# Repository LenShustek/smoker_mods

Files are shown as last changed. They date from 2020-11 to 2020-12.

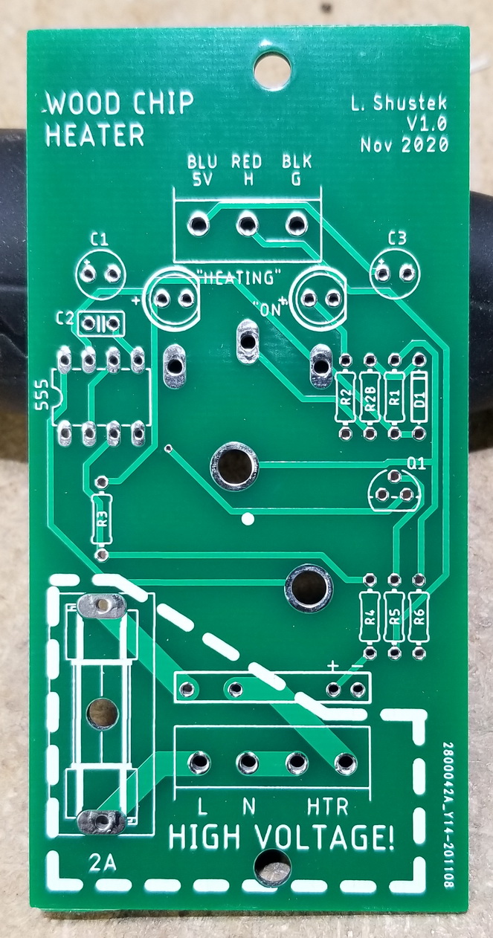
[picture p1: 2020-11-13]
chipheater/photos/PC_board.jpg

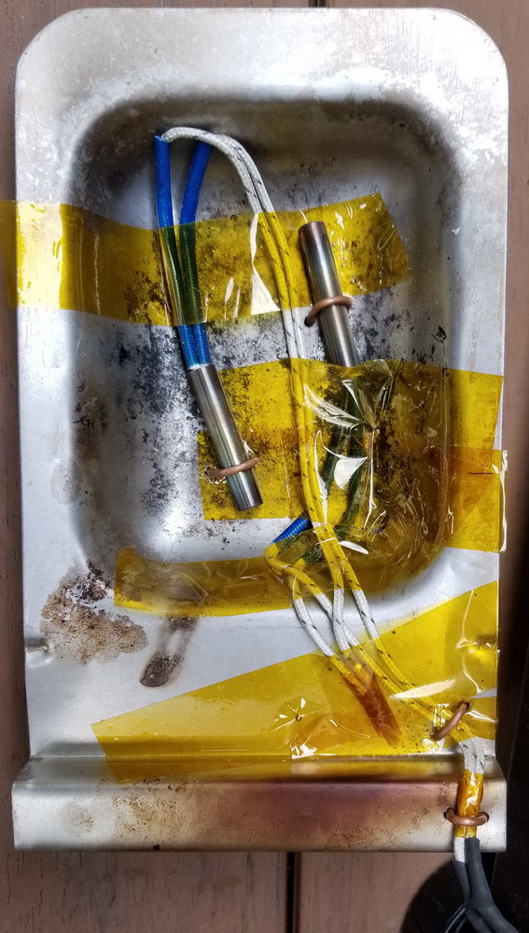
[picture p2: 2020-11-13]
chipheater/photos/chip_tray.jpg

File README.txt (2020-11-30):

This is a repository that documents my modifications to the 
Masterbuilt MES130B food smoker. 

It's a serviceable appliance, and we've made some great meals with it, 
but it suffers from a number of defects. You can read my posting to 
www.smokingmeatforums.com about them in the file forum_posting.txt. 

The first modification I made is to keep the smoke production going 
when the main (and only) heating element turns off to allow the 
temperature to come down. I put some heating elements in the bottom of 
the wood chip tray, and turn them on periodically whenever the main 
heater is off. 

The details are in the chipheater directory. There are two 100W heating 
elements wired in series, so 50W power dissipation. To control them I 
tapped into the 4-wire cable (ground, 5VDC power, heater on, and 
temperature sense) that goes to Masterbuilt's controller, and connected 
a little circuit that switches a small solid-state relay. A knob adjusts 
the duty cycle: it's on for 10 seconds and off for 2 to 18 seconds. It 
seems to be working fine. 

The second modification was to replace the Masterbuilt controller with
one based on an inexpensive PID (proportional-integral-differential) 
controller, interfaced to the smoker with a small circuit. This keeps
the temperature at the set point within a degree or two, rather than
having huge overshoot and undershoot by 10-15 degrees in each direction, 
with a cycle time of about 15 minutes. 

The details are in the PID_interface directory. In particular, see
the PID_addition_instructions file for instructions and photos.
This modification doesn't require the smoker unit itself to be
taken apart, or any of its 120V AC wiring changed.

Len Shustek 13 November 2020 
updated 29 November 2020

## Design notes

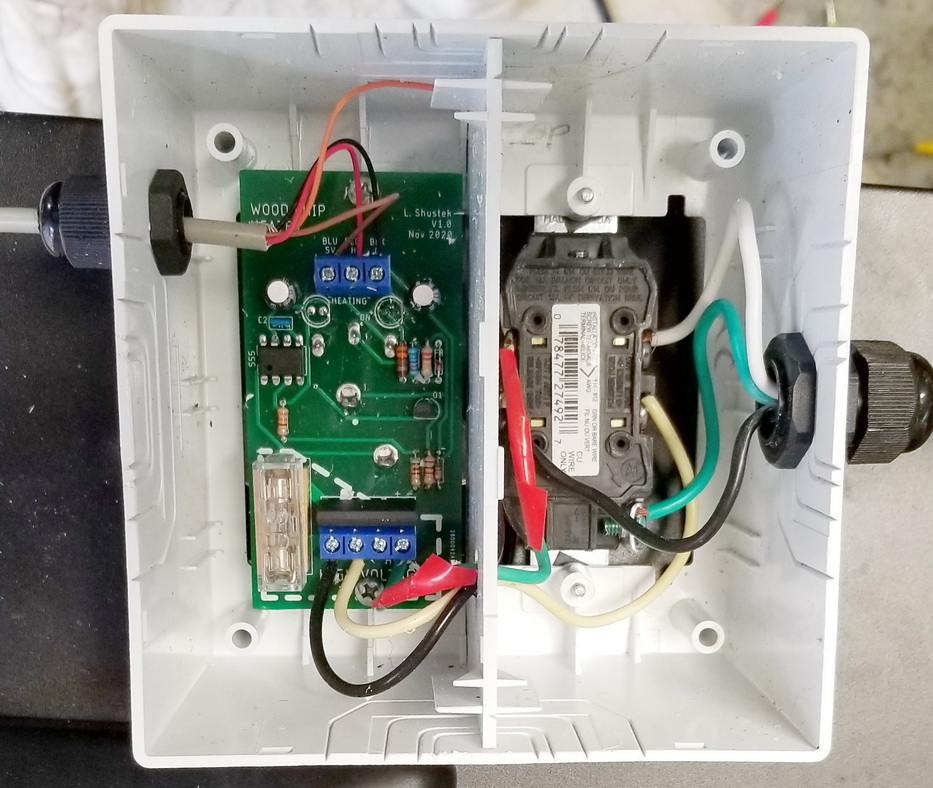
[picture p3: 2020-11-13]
chipheater/photos/inside.jpg

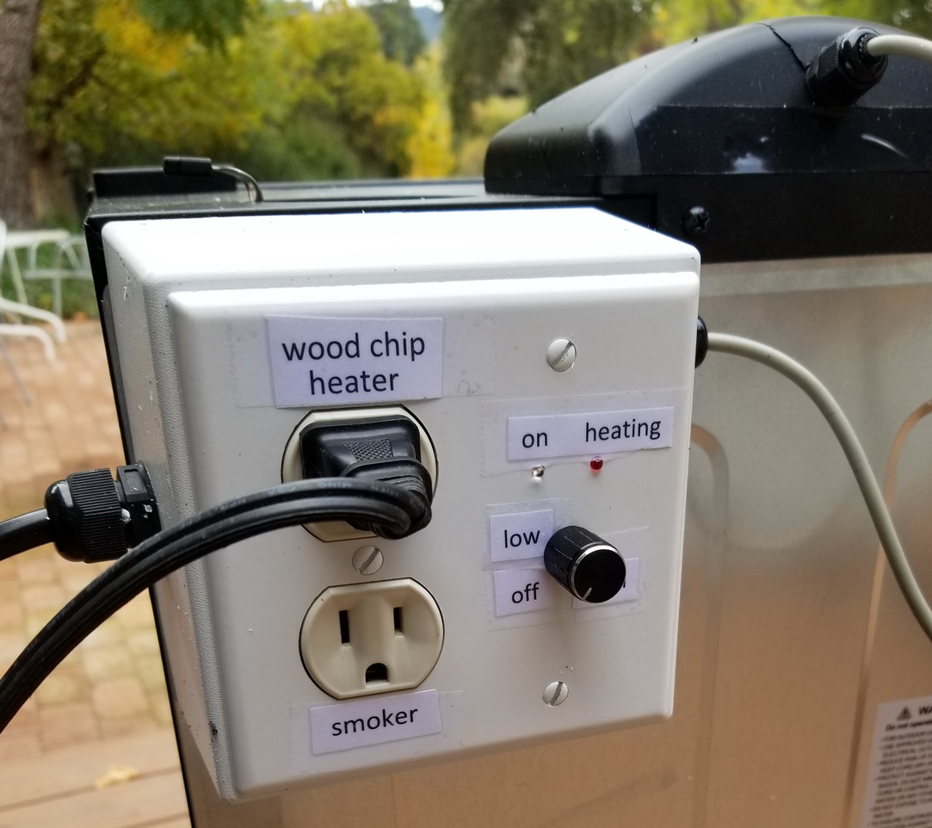
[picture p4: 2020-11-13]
chipheater/photos/outside.jpg

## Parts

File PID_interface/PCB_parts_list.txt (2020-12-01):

Masterbuilt MES 130B to REX-C100 PID controller interface 
printed circuit board parts list

R1: 5.1K ohm 1/4 watt resistor
R2: 3.3K ohm 1/4 watt resistor
R3: 1K ohm 1/4 watt resistor
D1: 1N4733 5.1 volt 1 watt zener diode
4-pin single-row 0.1" spacing pin header
2-pin 0.2" spacing PCB mount screw terminal connector
3-pin 0.2" spacing PCB mount screw terminal connector (only needed for chip heater)

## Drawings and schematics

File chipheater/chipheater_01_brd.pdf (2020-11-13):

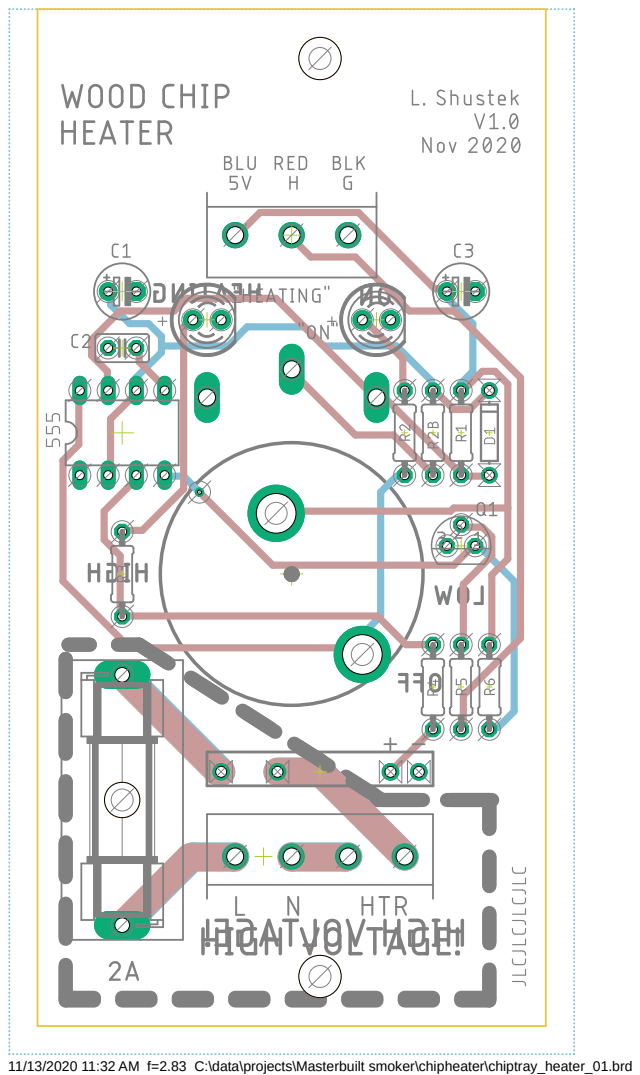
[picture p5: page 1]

11/13/2020 11:32 AM f=2.83 C:\data\projects\Masterbuilt smoker\chipheater\chiptray_heater_01.brd

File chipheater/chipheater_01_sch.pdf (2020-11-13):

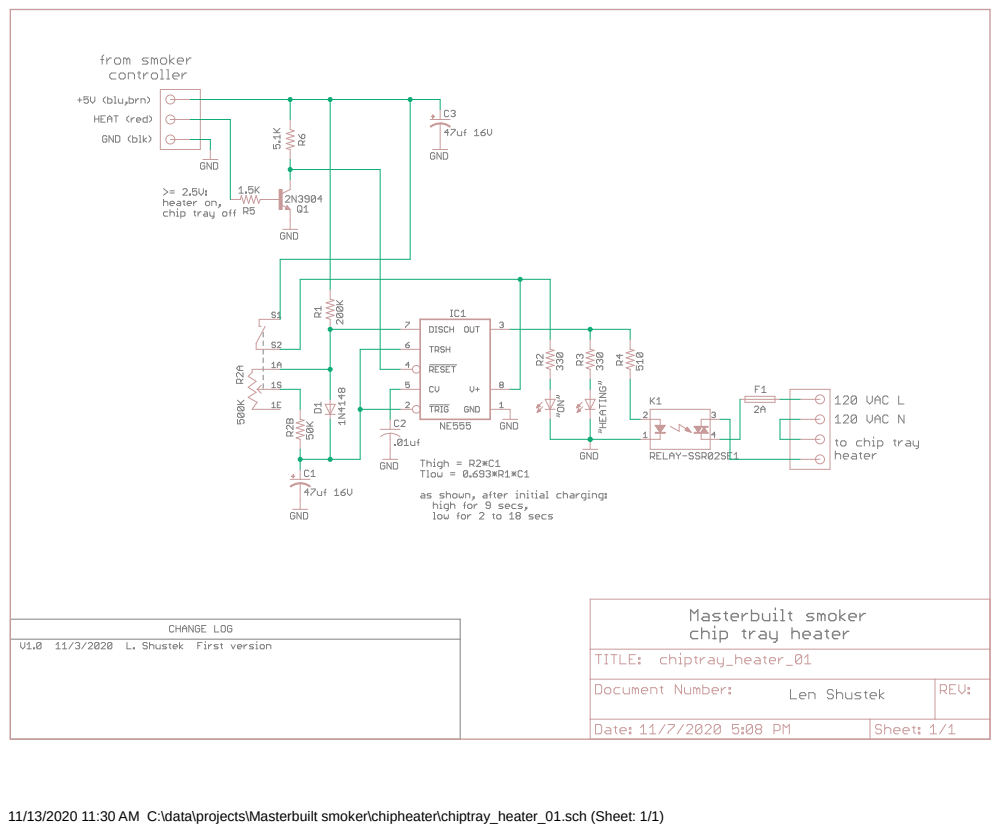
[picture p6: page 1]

11/13/2020 11:30 AM C:\data\projects\Masterbuilt smoker\chipheater\chiptray_heater_01.sch (Sheet: 1/1)

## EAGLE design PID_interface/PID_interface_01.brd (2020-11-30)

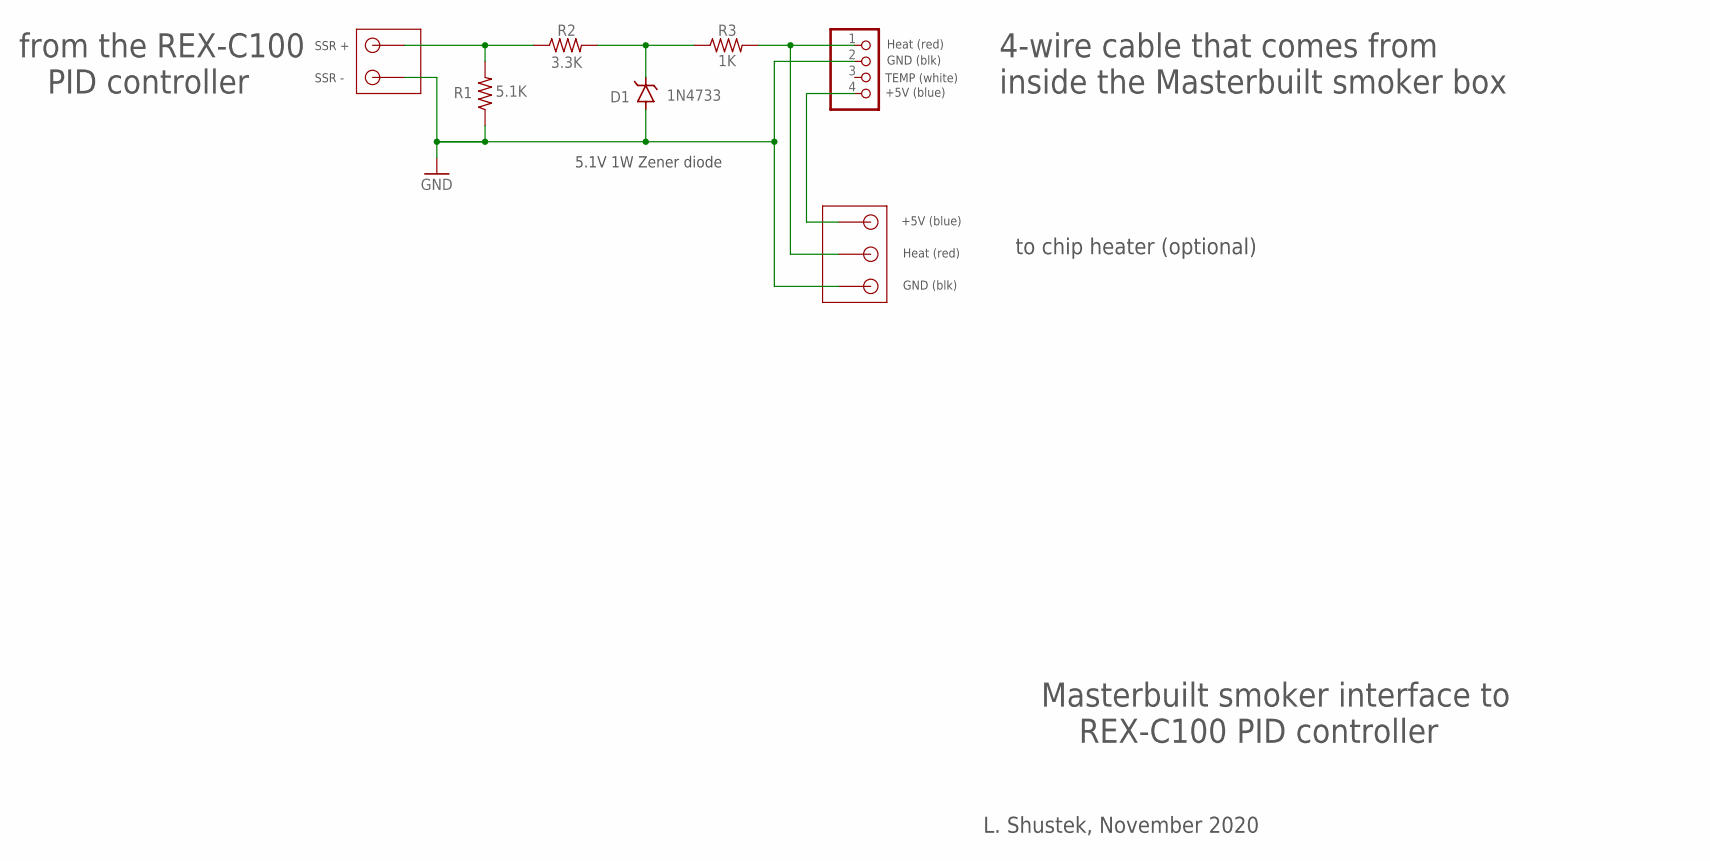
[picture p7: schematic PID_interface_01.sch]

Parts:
D1: 1N4733; DO35-10
JP1: PINHD-1X4; 1X04
R1: 5.1K; 0207/10
R2: 3.3K; 0207/10
R3: 1K; 0207/10
U$1: CONNECTOR-2PINTHIN; CONNECTOR-2PIN-5MM_THIN
U$2: CONNECTOR-3PIN; CONNECTOR-3PIN-5MM_THIN

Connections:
+5V: JP1.4, U$2.P$1
GND: D1.A, JP1.2, R1.1, U$1.P$1, U$2.P$3
HEAT: JP1.1, R3.2, U$2.P$2
unnamed: R1.2, R2.1, U$1.P$2
unnamed: D1.C, R2.2, R3.1

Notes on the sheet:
Masterbuilt smoker interface to REX-C100 PID controller
L. Shustek, November 2020
Heat (red)
GND (blk)
TEMP (white)
+5V (blue)
4-wire cable that comes from inside the Masterbuilt smoker box
SSR -
SSR +
from the REX-C100 PID controller
5.1V 1W Zener diode
to chip heater (optional)

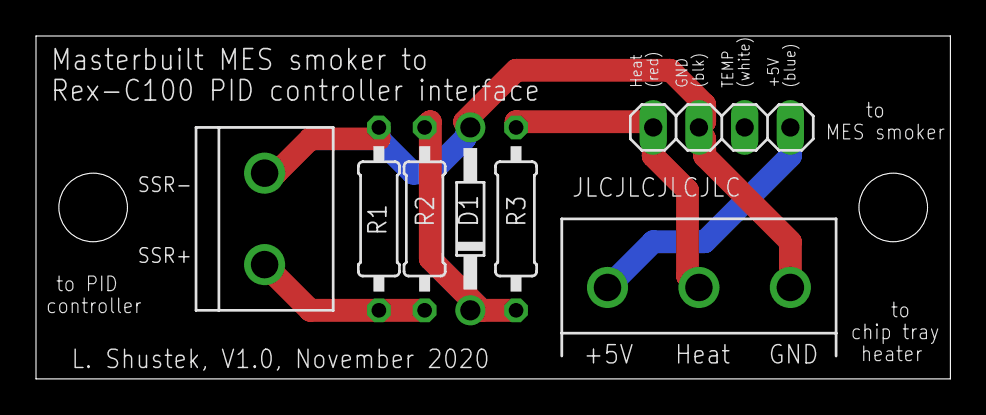
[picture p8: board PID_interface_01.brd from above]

Board: 2 copper layers, 50.8 x 19.1 mm, 7 parts (0 on the bottom side), 5 nets.

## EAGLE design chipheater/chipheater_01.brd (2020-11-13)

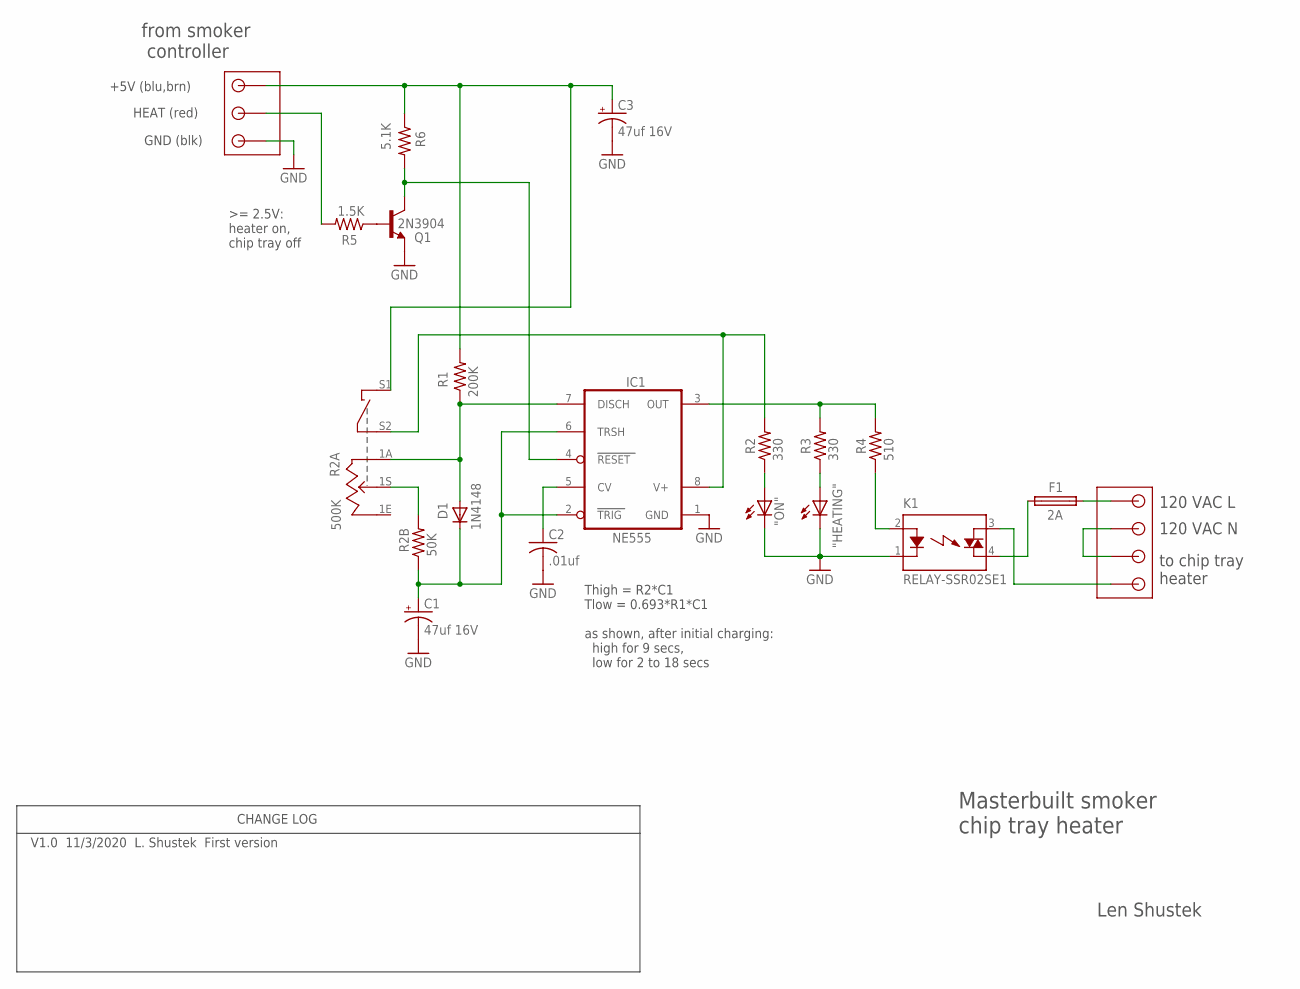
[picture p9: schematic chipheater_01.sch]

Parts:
"HEATING": LED5MM
"ON": LED5MM
C1, C3: 47uf 16V; E2,5-5
C2: .01uf; C025-025X050
D1: 1N4148; DO-1N4148
F1: 2A; SH22,5A
IC1: NE555; DIL08
K1: RELAY-SSR02SE1; RELAY-SSR
Q1: 2N3904; TO92
R1: 200K; 0204/7
R2, R3: 330; 0204/7
R2A: 500K; POT_W/SWITCH-UXCELL
R2B: 50K; 0204/7
R4: 510; 0204/7
R5: 1.5K; 0204/7
R6: 5.1K; 0204/7
U$1: CONNECTOR-4PIN; CONNECTOR-4PIN-5MM_THIN
U$2: CONNECTOR-3PIN; CONNECTOR-3PIN-5MM_THIN

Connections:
-RESET: IC1.4 (RESET), Q1.1 (C), R6.2
AC-L: F1.2, U$1.P$1
AC-N: U$1.P$2, U$1.P$3
GND: "HEATING".K (C), "ON".K (C), C1.-, C2.2, C3.-, IC1.1 (GND), K1.1 (K), Q1.3 (E), U$2.P$1
HEAT: R5.2, U$2.P$2
HTR: K1.3 (DS1), U$1.P$4
unnamed: "ON".A, R2.1
unnamed: Q1.2 (B), R5.1
unnamed: F1.1, K1.4 (DS2)
unnamed: IC1.8 (V+), R2.2, R2A.S2
unnamed: K1.2 (A), R4.1
unnamed: D1.A, IC1.7 (DISCH), R1.1, R2A.1A
unnamed: R2A.1S, R2B.2
unnamed: C2.1, IC1.5 (CV)
unnamed: C1.+, D1.C, IC1.2 (TRIG), IC1.6 (TRSH), R2B.1
unnamed: IC1.3 (OUT), R3.2, R4.2
unnamed: "HEATING".A, R3.1
VCC: C3.+, R1.2, R2A.S1, R6.1, U$2.P$3

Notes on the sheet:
Masterbuilt smoker chip tray heater
Len Shustek
V1.0 11/3/2020 L. Shustek First version
CHANGE LOG
120 VAC L
120 VAC N
to chip tray heater
+5V (blu,brn)
GND (blk)
HEAT (red)
from smoker controller
Thigh = R2*C1 Tlow = 0.693*R1*C1 as shown, after initial charging: high for 9 secs, low for 2 to 18 secs

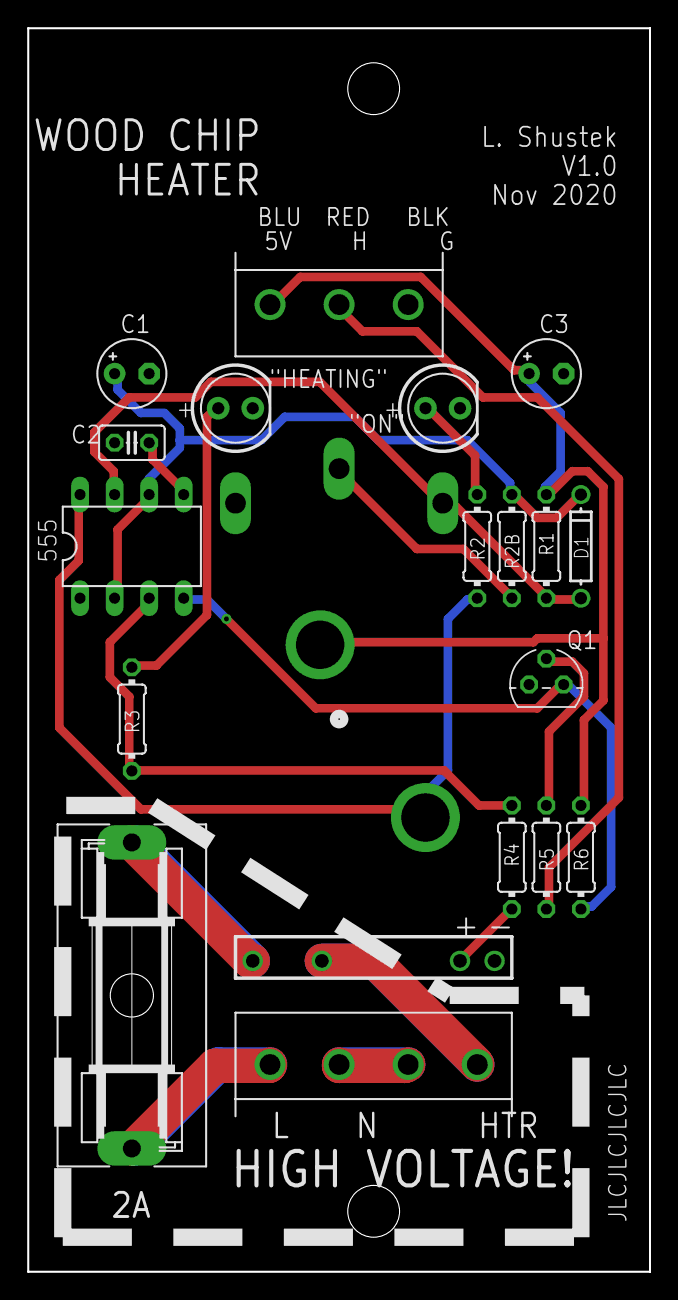
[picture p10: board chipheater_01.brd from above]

Board: 2 copper layers, 45.7 x 91.4 mm, 20 parts (1 on the bottom side), 18 nets.

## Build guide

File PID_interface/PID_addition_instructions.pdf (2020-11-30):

## Masterbuilt MES 130B smoker PID controller addition

These are instructions for replacing the controller of the Masterbuilt MES 130B smoker with an inexpensive PID ("proportional-integral-differential") controller that holds the temperature close to the set point within a couple of degrees, instead of within 20 degrees like the Masterbuilt controller.

This project is based on the common and inexpensive ($20 or so) Rex C-100 PID controller. It also uses a small "PID interface" printed circuit board that I built, which replaces the Masterbuilt controller while still using the existing relay and 120 volt wiring in the smoker. You don’t need to open up access panels (or worse, drill out rivets) to rewire the heavy-duty power, or install a new relay and heat sink.

Masterbuilt has a bewildering number of different models. I don't know which other models this interface will work for. If the controller connects to the smoker with a 4-wire cable (blue, white, black, red), it has a good chance of working. There might be also be another temperature probe cable, but that won't matter; leave it unconnected. If their controller cable has more than 4 wires in it, you will need to do some reverse engineering; let me know what you discover.

The design of the interface board is free, at www.github.com/lenshustek/smoker_mods. It uses only three resistors, a Zener diode, and some connectors. I will make assembled boards available inexpensively, if I have any left, but this is not a business for me.

In fact, this is NOT A COMMERCIAL PRODUCT or even a KIT; it is a DO-IT-YOURSELF PROJECT. IT IS PROVIDED "AS IS", WITHOUT WARRANTY OF ANY KIND, EXPRESS OR IMPLIED, INCLUDING BUT NOT LIMITED TO THE WARRANTIES OF MERCHANTABILITY, FITNESS FOR A PARTICULAR PURPOSE AND NONINFRINGEMENT. IN NO EVENT SHALL I BE LIABLE FOR ANY CLAIM, DAMAGES OR OTHER LIABILITY, WHETHER IN AN ACTION OF CONTRACT, TORT OR OTHERWISE, ARISING FROM, OUT OF, OR IN CONNECTION WITH THIS DESIGN OR HARDWARE OR THE USE OR OTHER DEALINGS OF IT. BEWARE, TOO, THAT YOU ARE PROBABLY VOIDING YOUR WARRANTY FROM MASTERBUILT BY DOING THIS.

No, I’m not a lawyer. I’m an engineer.

Are you in anyway? If so, here are the steps you need to take:

- Buy a Rex C-100 PID controller. There are lots of them to be had on eBay, both the original version from the Japanese originator RKC instrument, and various Chinese clones.
- Be sure to get one configured for K-type thermocouples and SSR relay output, which is also called "pulse output". The model number I've used is C100FK02-V*AN.
- Build or buy one of the little interface boards with the 3 resistors and one diode.
- Wire up stuff as follows:
- Connect the two control (“SSR”) outputs on terminals 4 and 5 of the C-100 to the 2-wire connector on the interface board. Make sure + goes to + and – to –.
- Connect a K-type thermocouple to the C-100. The blue wire goes to terminal 9 and the red wire goes to terminal 10. I used a thermocouple with a 2” long probe ($8 at https://www.amazon.com/gp/product/B0748BQ3YL) so that I could screw it into a hole that I drilled and tapped in the side of the smoker. But you can install it in all sorts of ways, including running the cable between the door gasket and the frame and laying it on a shelf, or dropping it down a smoke vent hole in the top back.
- Connect the cable that went to the Masterbuilt controller to the 4-pin connector of the interface board instead, being careful to get the colors in the right order. Remove their controller.
- Connect 120 VAC power to terminals 1 and 2 of the C-100, in series with a switch so you can turn it on and off.
- In the unlikely event that you have also built my wood chip tray heater board, https://github.com/LenShustek/smoker_mods/tree/master/chipheater, connect the two boards together using the three-wire connectors on each.
- Of course, it should all be in a nice box and wired in a careful and safe manner. My photos at the end of this document can give you some ideas, but be creative. I used this 4.7”x4.7”x3.5” plastic project box mounted on a slanted wooden shim that goes where the original controller was: https://www.amazon.com/gp/product/B083H9G123.
- Make a few parameter changes in the C-100 when you power it up for the first time. You do that by holding down the “SET” button for a couple of seconds until the display shows “AL 1”. Then push the SET button repeatedly to get to the parameter to be changed, then use the arrows to change the various digits.
- The following changes are PID values that work for me and are a good starting point. See the “auto tune” section later about making your own changes.
- r (cycle time in seconds): 10 instead of 2. This keeps the mechanical relay in the smoker from changing too frequently.
- P (proportional coefficient): 34 instead of 30
- I (integral coefficient): 472 instead of 120
- D (differential coefficient): 118 instead of 30
- Press and hold SET to exit.
- If your unit’s display is in Centigrade and you want to change it to Fahrenheit, you need to do that in the “instrument engineer menu”:
- Press the SET key and the left arrow key together for about 3 seconds, and it should display “Cod”. Change Cod to 1 with the up-arrow key.
- Press the SET button repeatedly until it shows “Unt” (unit), and change the value from 0 to 1 with the up-arrow key.
- Press and hold SET to exit.
- To start smoking, use the up and down arrows to set the target temperature (SV: “Set Value”) and watch the current temperature (PV: “Present Value”).

Auto-tuning

The PID values above work well for me, and are a good starting point, but you can experiment with having the Rex C-100 tune itself for your configuration.

- Set up the unit as normal. Maybe put a 10- or 15-pound pan of water inside to simulate the thermal load of food.
- Set the temperature to 210F and let it get up to about 175F.

- Change the ATU (auto-tune) parameter to 1.
- The "auto" light will come on. Let it run for 15 minutes or so, after which it should turn off by itself. If it doesn't go off after 20 minutes, set ATU back to 0 to stop the auto-tuning session.
- Look at the P, I, and D parameters to see how they were changed. Try that for a while.
Lather, rinse, repeat: if you auto-tune again, it will tweak the values.

If you build this, let me know how it goes. Maybe post about your experience in this thread at SmokingMeatForums: https://www.smokingmeatforums.com/threads/a-newbies-technical-review-and-mods-to-a-masterbuilt-mes-smoker.302909/ (https://www.smokingmeatforums.com/threads/a-newbies-technical-review-and-mods-to-a-masterbuilt-mes-smoker.302909/)

Enjoy.

Len Shustek
29 November 2020

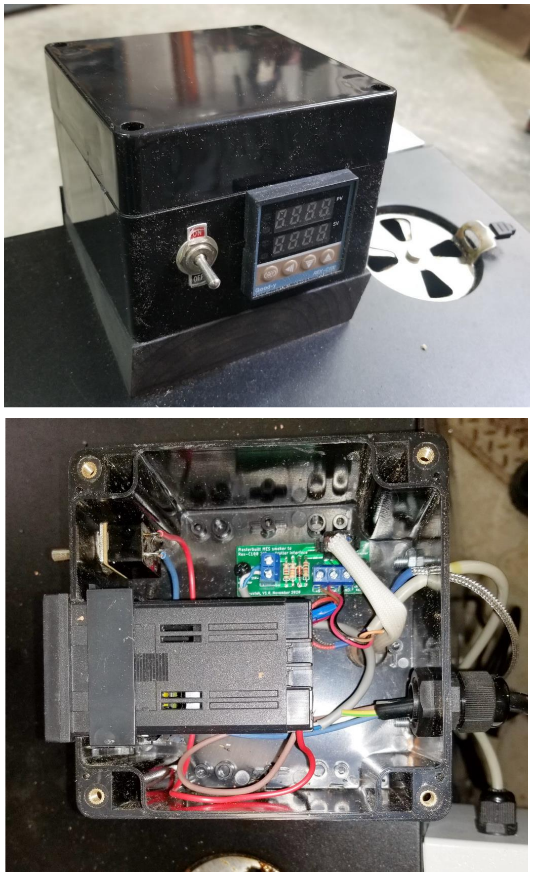
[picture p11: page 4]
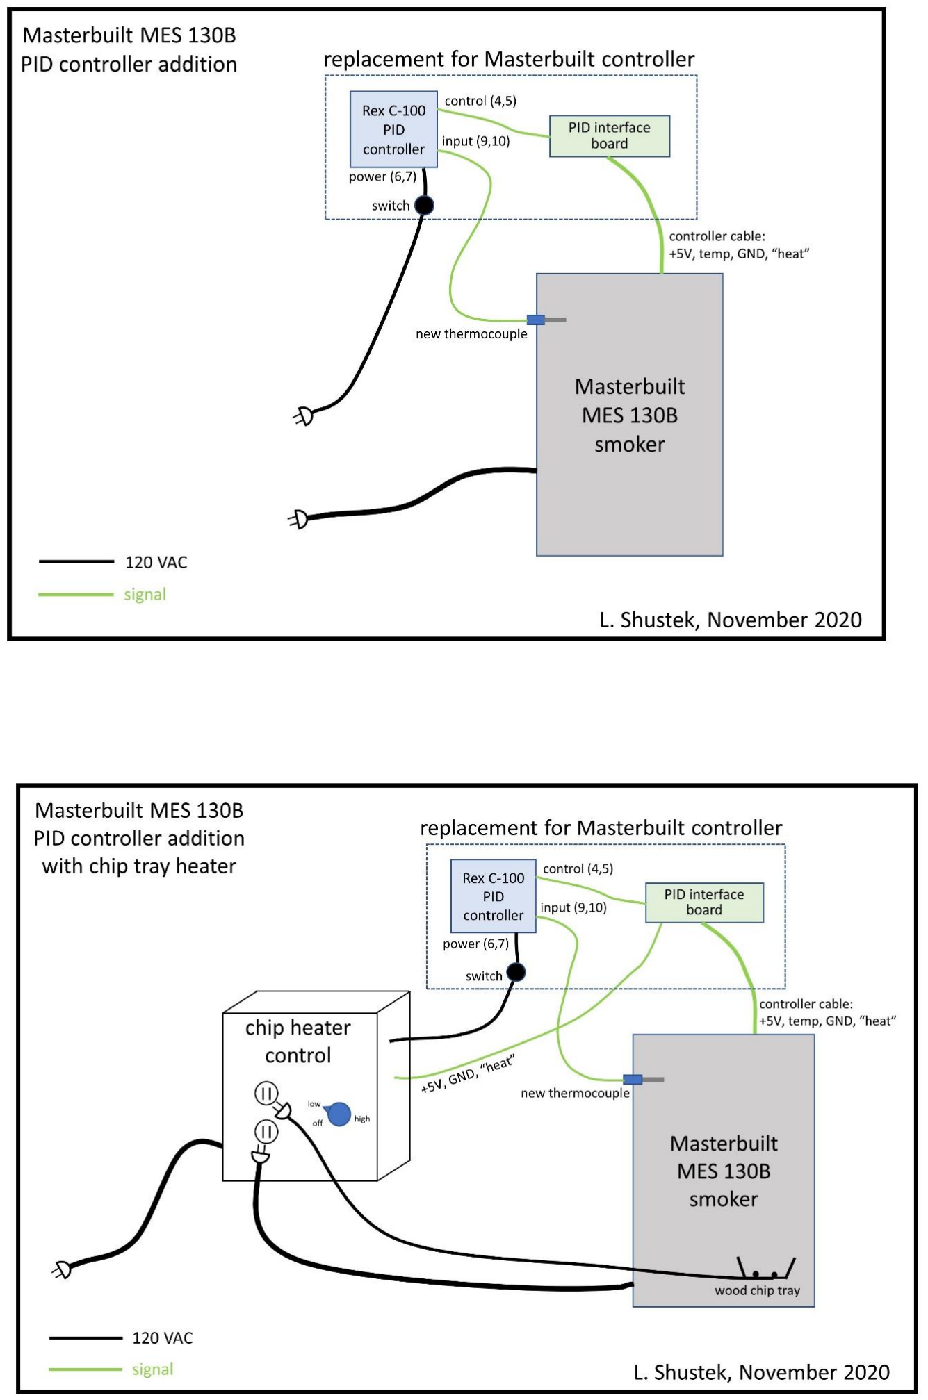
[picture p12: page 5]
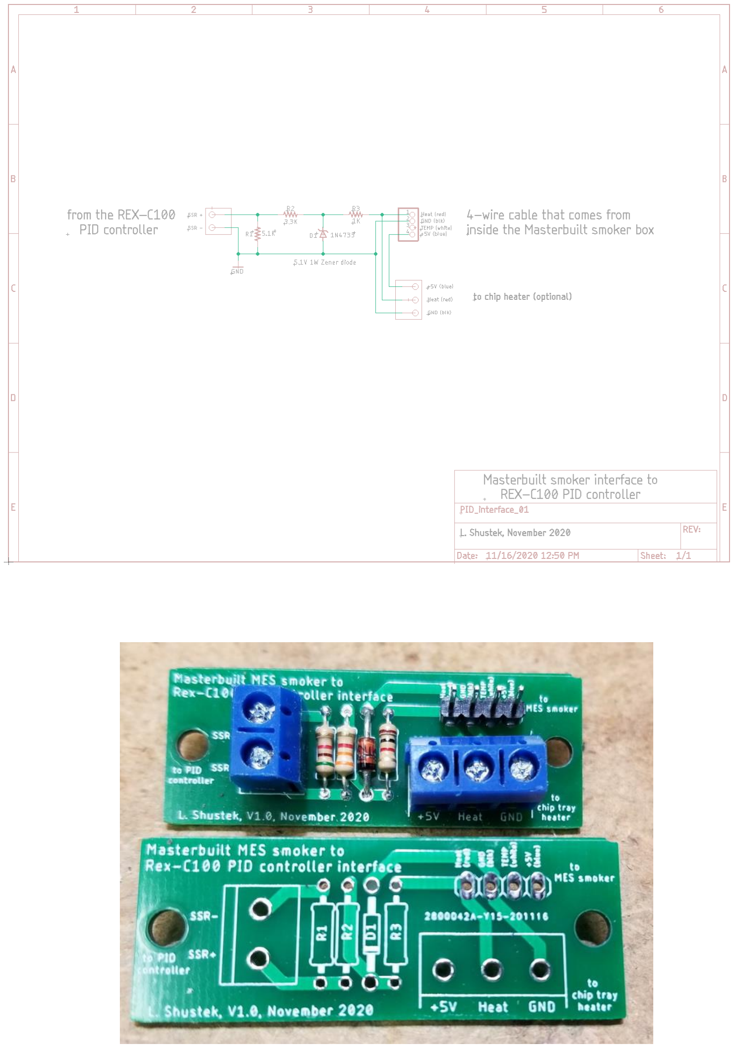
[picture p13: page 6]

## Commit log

2020-11-13 Initial posting
    [chipheater_01.brd, chipheater_01.sch]
2020-11-30 PID controller mod
    [PID_interface_01.brd, PID_interface_01.sch]
